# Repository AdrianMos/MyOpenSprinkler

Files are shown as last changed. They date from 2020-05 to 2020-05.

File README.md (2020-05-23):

# myOpenSprinkler
open-source RaspberryPi sprinkler valve controller

This repo includes the KiCad project.

**Features:**
- designed for RaspberryPi Zero W
- small form factor

* inspired by OpenSprinkler Pi project
* supports OpenSprinkler software

- controls 8 zones (8x24VAC valves)
- optical insulation between the power-triacs and RaspberryPi 
- integrated 24VAC to 5V converter (no power connector required for RaspberryPi)
- includes a real-time-clock (RTC) module
- rain sensor input
- transient voltage protection

* connector for RFM12B radio transceiver (used for remote sensing/control)  [drivers not available yet]
* 1-wire communication for connecting external temperature sensors [drivers not available yet]

**Hardware v1.0:**

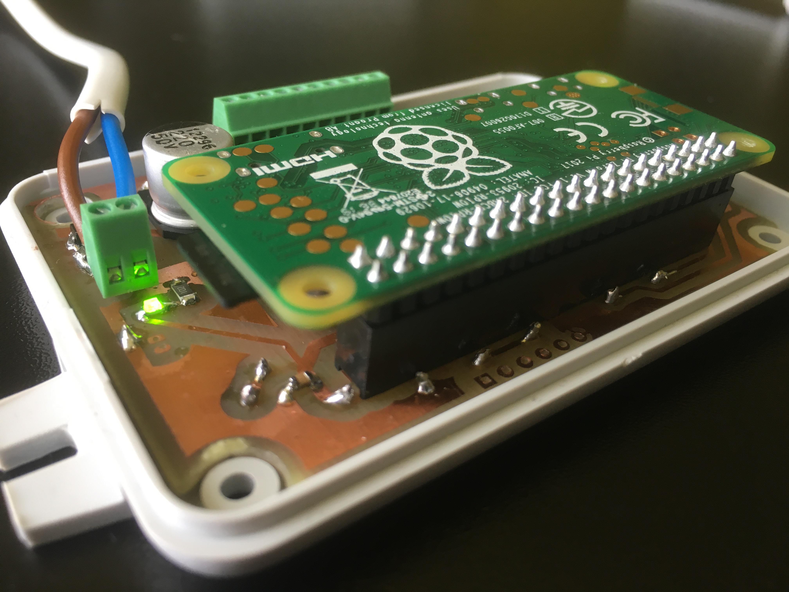
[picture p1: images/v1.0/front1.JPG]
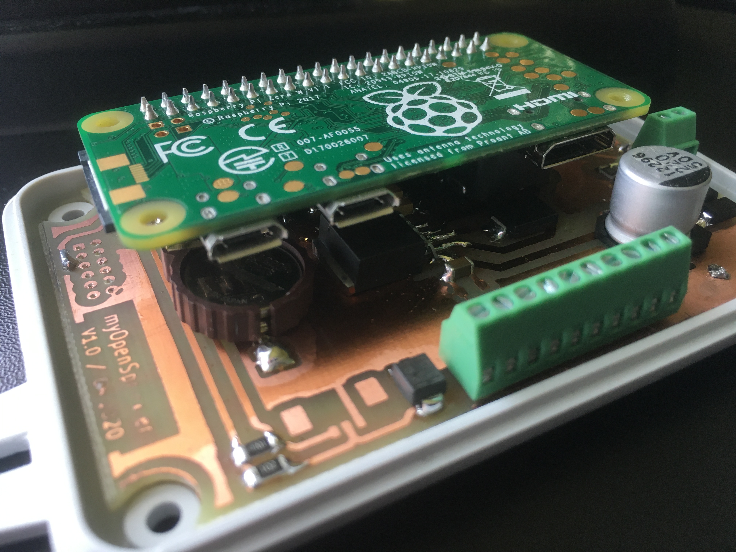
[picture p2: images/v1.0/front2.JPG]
 
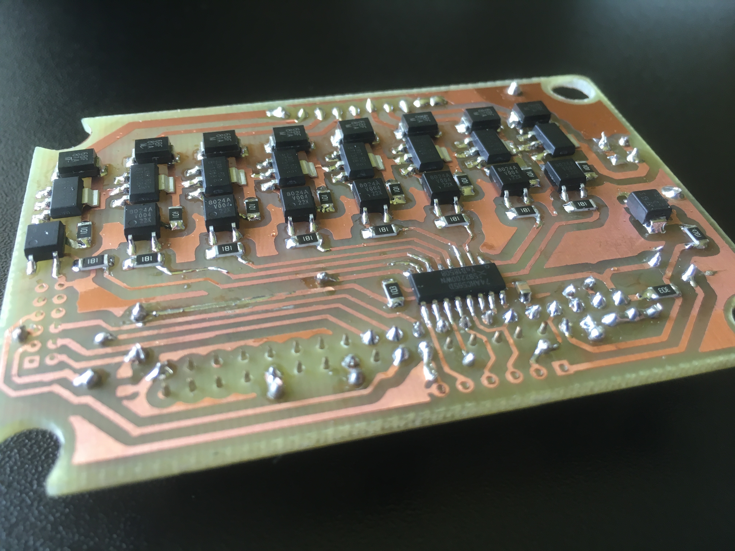
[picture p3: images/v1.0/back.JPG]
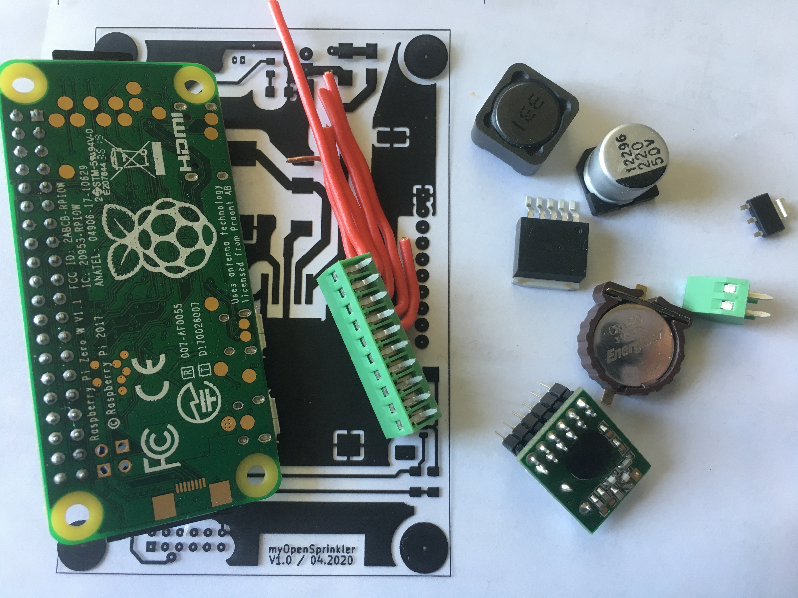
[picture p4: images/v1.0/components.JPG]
 
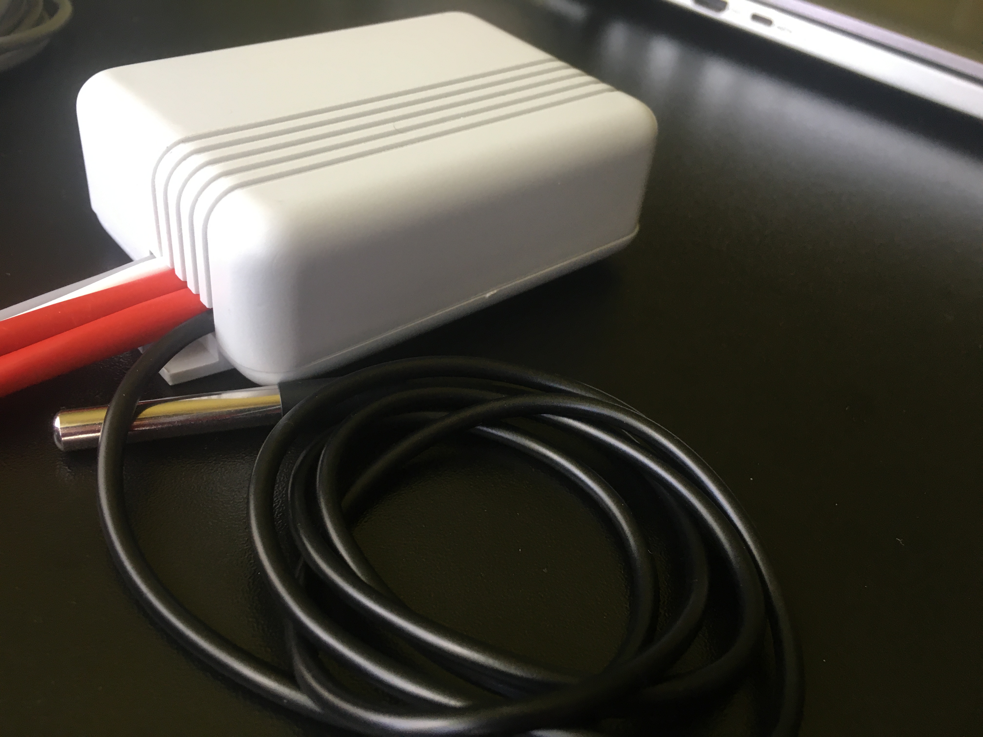
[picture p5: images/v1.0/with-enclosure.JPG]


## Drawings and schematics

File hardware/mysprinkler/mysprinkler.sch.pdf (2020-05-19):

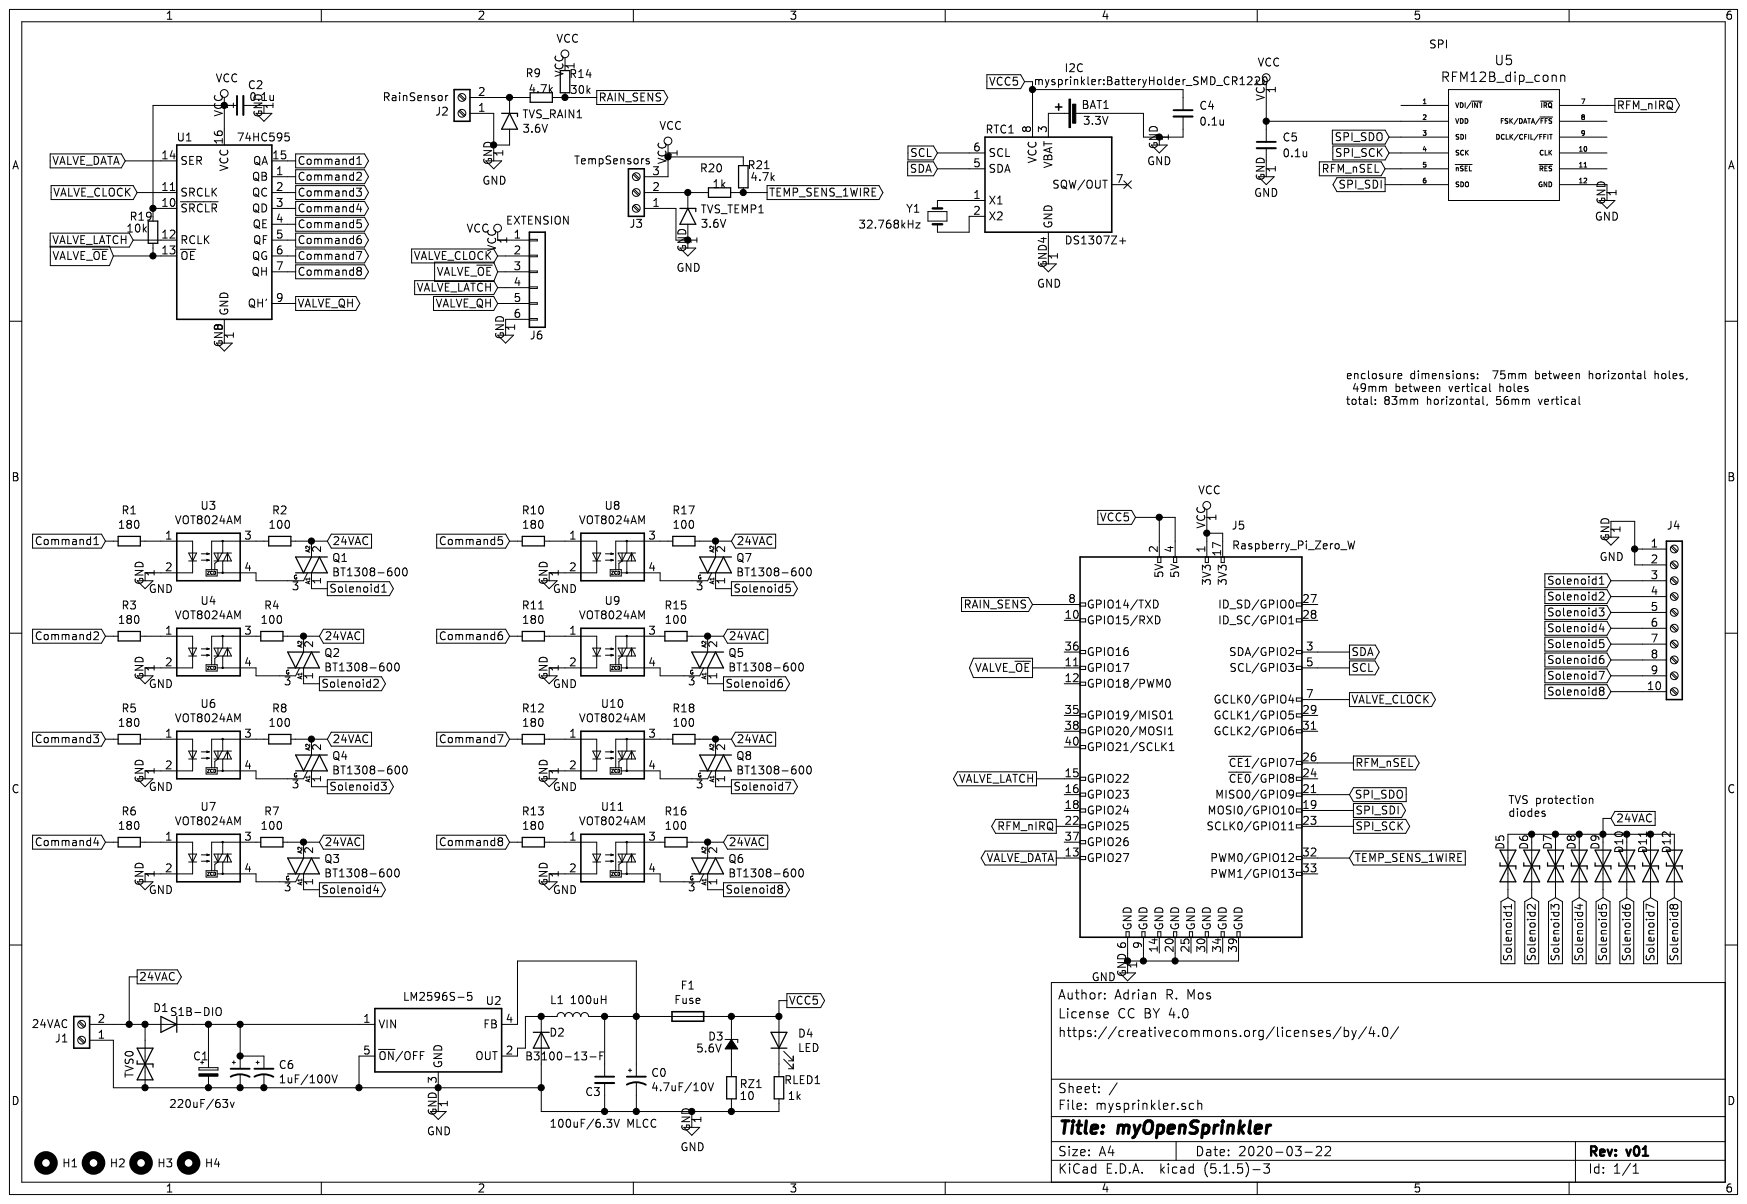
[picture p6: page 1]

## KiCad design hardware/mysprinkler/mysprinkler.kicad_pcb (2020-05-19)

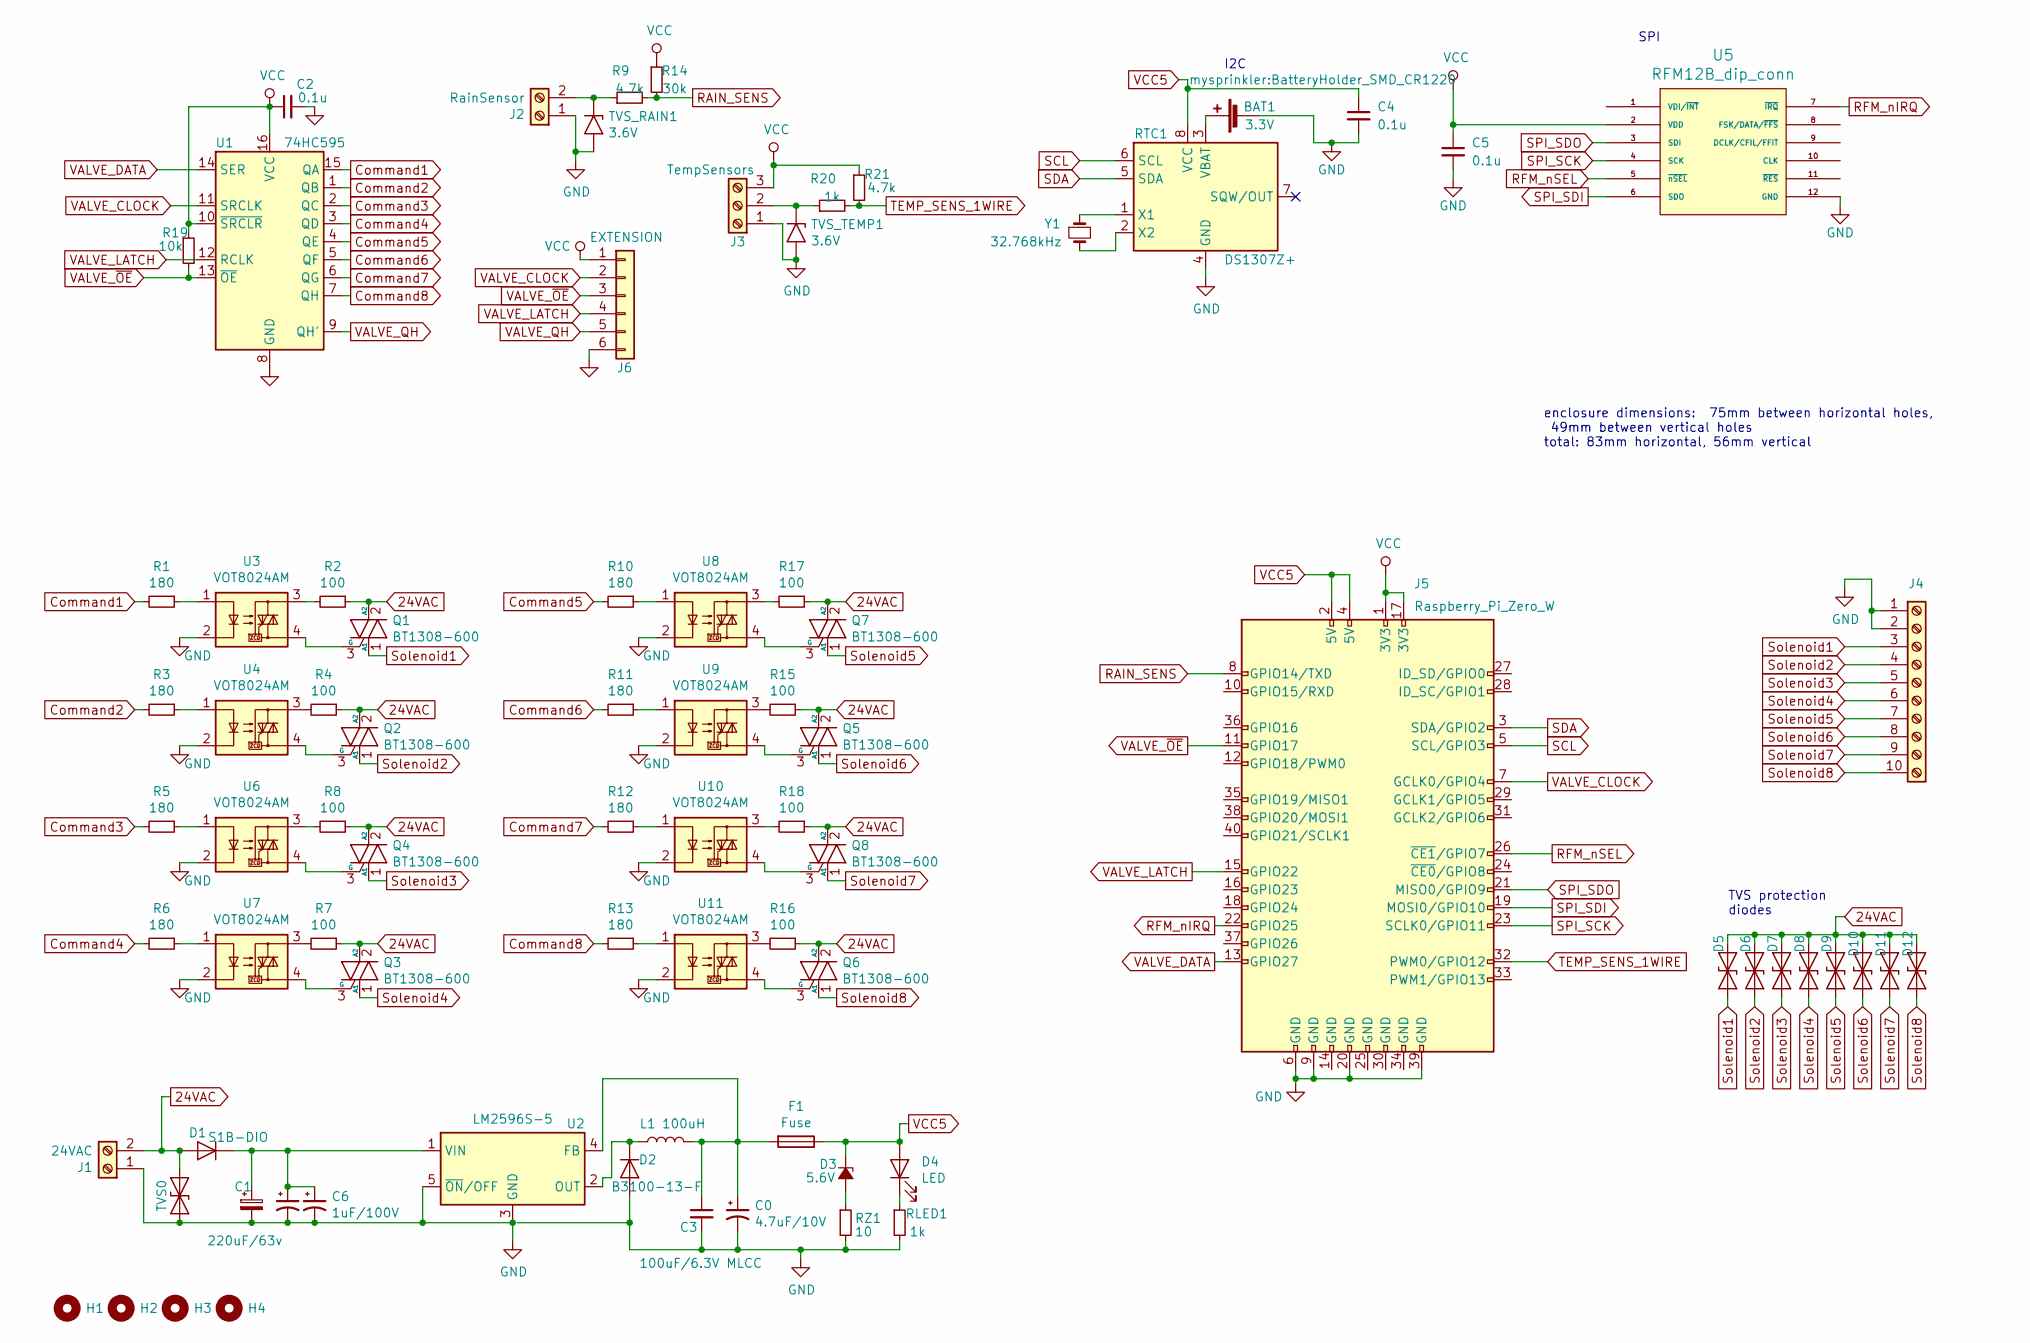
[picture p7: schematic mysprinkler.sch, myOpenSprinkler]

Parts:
BAT1: 3.3V; BatteryHolder_SMD_CR1220
C0: 4.7uF/10V; CP_EIA-3216-18_Kemet-A_Pad1.58x1.35mm_HandSolder
C1: 220uF/63v; C_Elec_10x10.2
C2, C4, C5: 0.1u; C_0805_2012Metric_Pad1.15x1.40mm_HandSolder
C3: 100uF/6.3V MLCC; CP_EIA-3528-21_Kemet-B_Pad1.50x2.35mm_HandSolder
C6: 1uF/100V; C_1206_3216Metric
C6b1: 2.2uF/100V; C_1206_3216Metric
D1: S1B-DIO; D_SMA
D2: B3100-13-F; D_SMC
D3: 5.6V; D_MiniMELF
D4: LED; LED_0805_2012Metric_Pad1.15x1.40mm_HandSolder
D5, D6, D7, D8, D9, D10, D11, D12: D_TVS; D_SMB
F1: Fuse; R_1812_4532Metric_Pad1.30x3.40mm_HandSolder
H1: MH1; MountingHole_6.4mm_M6
H2: 2; MountingHole_6.4mm_M6
H3: 3; MountingHole_6.4mm_M6
H4: 4; MountingHole_6.4mm_M6
J1: 24VAC; TerminalBlock_TE_282834-2_1x02_P2.54mm_Horizontal
J2: RainSensor; Molex_PicoBlade_53047-0210_1x02_P1.25mm_Vertical
J3: TempSensors; Molex_PicoBlade_53398-0371_1x03-1MP_P1.25mm_Vertical
J4: Screw_Terminal_01x10; TerminalBlock_TE_1-282834-0_1x10_P2.54mm_Horizontal
J5: Raspberry_Pi_Zero_W; RaspberryPi_connector_female
J6: EXTENSION; PinHeader_1x06_P2.54mm_Vertical
L1: 100uH; L_12x12mm_H8mm
Q1, Q2, Q3, Q4, Q5, Q6, Q7, Q8: BT1308-600; SOT-223-3_TabPin2
R1, R3, R5, R6, R10, R11, R12, R13: 180; R_1206_3216Metric_Pad1.42x1.75mm_HandSolder
R2, R4, R7, R8, R15, R16, R17, R18: 100; R_1206_3216Metric_Pad1.42x1.75mm_HandSolder
R9, R21: 4.7k; R_1206_3216Metric_Pad1.42x1.75mm_HandSolder
R14: 30k; R_1206_3216Metric_Pad1.42x1.75mm_HandSolder
R19: 10k; R_1206_3216Metric_Pad1.42x1.75mm_HandSolder
R20: 1k; R_1206_3216Metric_Pad1.42x1.75mm_HandSolder
RLED1: 1k; R_1206_3216Metric_Pad1.42x1.75mm_HandSolder
RTC1: DS1307Z+; SOIC-8_3.9x4.9mm_P1.27mm
RZ1: 10; R_1206_3216Metric_Pad1.42x1.75mm_HandSolder
TVS0: D_TVS; D_SMB
TVS_RAIN1: 3.6V; D_SMB
TVS_TEMP1: 3.6V; D_SMB
U1: 74HC595; SOIC-16_3.9x9.9mm_P1.27mm
U2: LM2596S-5; TO-263-5_TabPin3
U3, U4, U6, U7, U8, U9, U10, U11: VOT8024AM; SO-4_4.4x4.3mm_P2.54mm_handsolder
U5: RFM12B_dip_conn; PinSocket_2x06_P2.00mm_Vertical
Y1: 32.768kHz; Crystal_SMD_EuroQuartz_EQ161-2Pin_3.2x1.5mm_HandSoldering

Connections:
24VAC: D1.2 (A), D5.2 (A2), D6.2 (A2), D7.2 (A2), D8.2 (A2), D9.2 (A2), D10.2 (A2), D11.2 (A2), D12.2 (A2), J1.2, Q1.2 (A2), Q2.2 (A2), Q3.2 (A2), Q4.2 (A2), Q5.2 (A2), Q6.2 (A2), Q7.2 (A2), Q8.2 (A2), R2.1, R4.1, R7.1, R8.1, R15.1, R16.1, R17.1, R18.1, TVS0.2 (A2)
Command1: R1.2, U1.15 (QA)
Command2: R3.2, U1.1 (QB)
Command3: R5.2, U1.2 (QC)
Command4: R6.2, U1.3 (QD)
Command5: R10.2, U1.4 (QE)
Command6: R11.2, U1.5 (QF)
Command7: R12.2, U1.6 (QG)
Command8: R13.2, U1.7 (QH)
GND: BAT1.2 (-), C0.2, C1.2, C2.2, C3.2, C4.2, C5.2, C6.2, C6b1.2, D2.2 (A), J1.1, J2.1, J3.1, J4.1, J4.2, J5.6 (GND), J5.9 (GND), J5.20 (GND), J5.39 (GND), J6.6, RLED1.2, RTC1.4 (GND), RZ1.2, TVS0.1 (A1), TVS_RAIN1.2 (A2), TVS_TEMP1.2 (A2), U1.8 (GND), U2.3 (GND), U2.5 (~ON~/OFF), U3.2, U4.2, U5.12 (GND), U6.2, U7.2, U8.2, U9.2, U10.2, U11.2
unnamed: BAT1.1 (+), RTC1.3 (VBAT)
unnamed: C0.1, C3.1, F1.2, L1.2, U2.4 (FB)
unnamed: C1.1, C6.1, C6b1.1, D1.1 (K), U2.1 (VIN)
unnamed: D2.1 (K), L1.1, U2.2 (OUT)
unnamed: D3.2 (A), RZ1.1
unnamed: D4.1 (K), RLED1.1
unnamed: J2.2, R9.1, TVS_RAIN1.1 (A1)
unnamed: J3.2, R20.1, TVS_TEMP1.1 (A1)
unnamed: Q1.3 (G), U3.4
unnamed: Q2.3 (G), U4.4
unnamed: Q3.3 (G), U7.4
unnamed: Q4.3 (G), U6.4
unnamed: Q5.3 (G), U9.4
unnamed: Q6.3 (G), U11.4
unnamed: Q7.3 (G), U8.4
unnamed: Q8.3 (G), U10.4
unnamed: R1.1, U3.1
unnamed: R2.2, U3.3
unnamed: R3.1, U4.1
unnamed: R4.2, U4.3
unnamed: R5.1, U6.1
unnamed: R6.1, U7.1
unnamed: R7.2, U7.3
unnamed: R8.2, U6.3
unnamed: R10.1, U8.1
unnamed: R11.1, U9.1
unnamed: R12.1, U10.1
unnamed: R13.1, U11.1
unnamed: R15.2, U9.3
unnamed: R16.2, U11.3
unnamed: R17.2, U8.3
unnamed: R18.2, U10.3
unnamed: RTC1.1 (X1), Y1.1
unnamed: RTC1.2 (X2), Y1.2
RAIN_SENS: J5.8 (GPIO14/TXD), R9.2, R14.2
RFM_nIRQ: J5.22 (GPIO25), U5.7 (~IRQ)
RFM_nSEL: J5.26 (~CE1~/GPIO7), U5.5 (~nSEL)
SCL: J5.5 (SCL/GPIO3), RTC1.6 (SCL)
SDA: J5.3 (SDA/GPIO2), RTC1.5 (SDA)
SPI_SCK: J5.23 (SCLK0/GPIO11), U5.4 (SCK)
SPI_SDI: J5.19 (MOSI0/GPIO10), U5.6 (SDO)
SPI_SDO: J5.21 (MISO0/GPIO9), U5.3 (SDI)
Solenoid1: D5.1 (A1), J4.3, Q1.1 (A1)
Solenoid2: D6.1 (A1), J4.4, Q2.1 (A1)
Solenoid3: D7.1 (A1), J4.5, Q4.1 (A1)
Solenoid4: D8.1 (A1), J4.6, Q3.1 (A1)
Solenoid5: D9.1 (A1), J4.7, Q7.1 (A1)
Solenoid6: D10.1 (A1), J4.8, Q5.1 (A1)
Solenoid7: D11.1 (A1), J4.9, Q8.1 (A1)
Solenoid8: D12.1 (A1), J4.10, Q6.1 (A1)
TEMP_SENS_1WIRE: J5.32 (PWM0/GPIO12), R20.2, R21.2
VALVE_CLOCK: J5.7 (GCLK0/GPIO4), J6.2, U1.11 (SRCLK)
VALVE_DATA: J5.13 (GPIO27), U1.14 (SER)
VALVE_LATCH: J5.15 (GPIO22), J6.4, U1.12 (RCLK)
VALVE_QH: J6.5, U1.9 (QH')
VALVE_~OE: J5.11 (GPIO17), J6.3, R19.2, U1.13 (~OE)
VCC: C2.1, C5.1, J3.3, J5.1 (3V3), J5.17 (3V3), J6.1, R14.1, R19.1, R21.1, U1.10 (~SRCLR), U1.16 (VCC), U5.2 (VDD)
VCC5: C4.1, D3.1 (K), D4.2 (A), F1.1, J5.2 (5V), J5.4 (5V), RTC1.8 (VCC)

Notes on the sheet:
TVS protection diodes
I2C
SPI
enclosure dimensions: 75mm between horizontal holes, 49mm between vertical holes total: 83mm horizontal, 56mm vertical

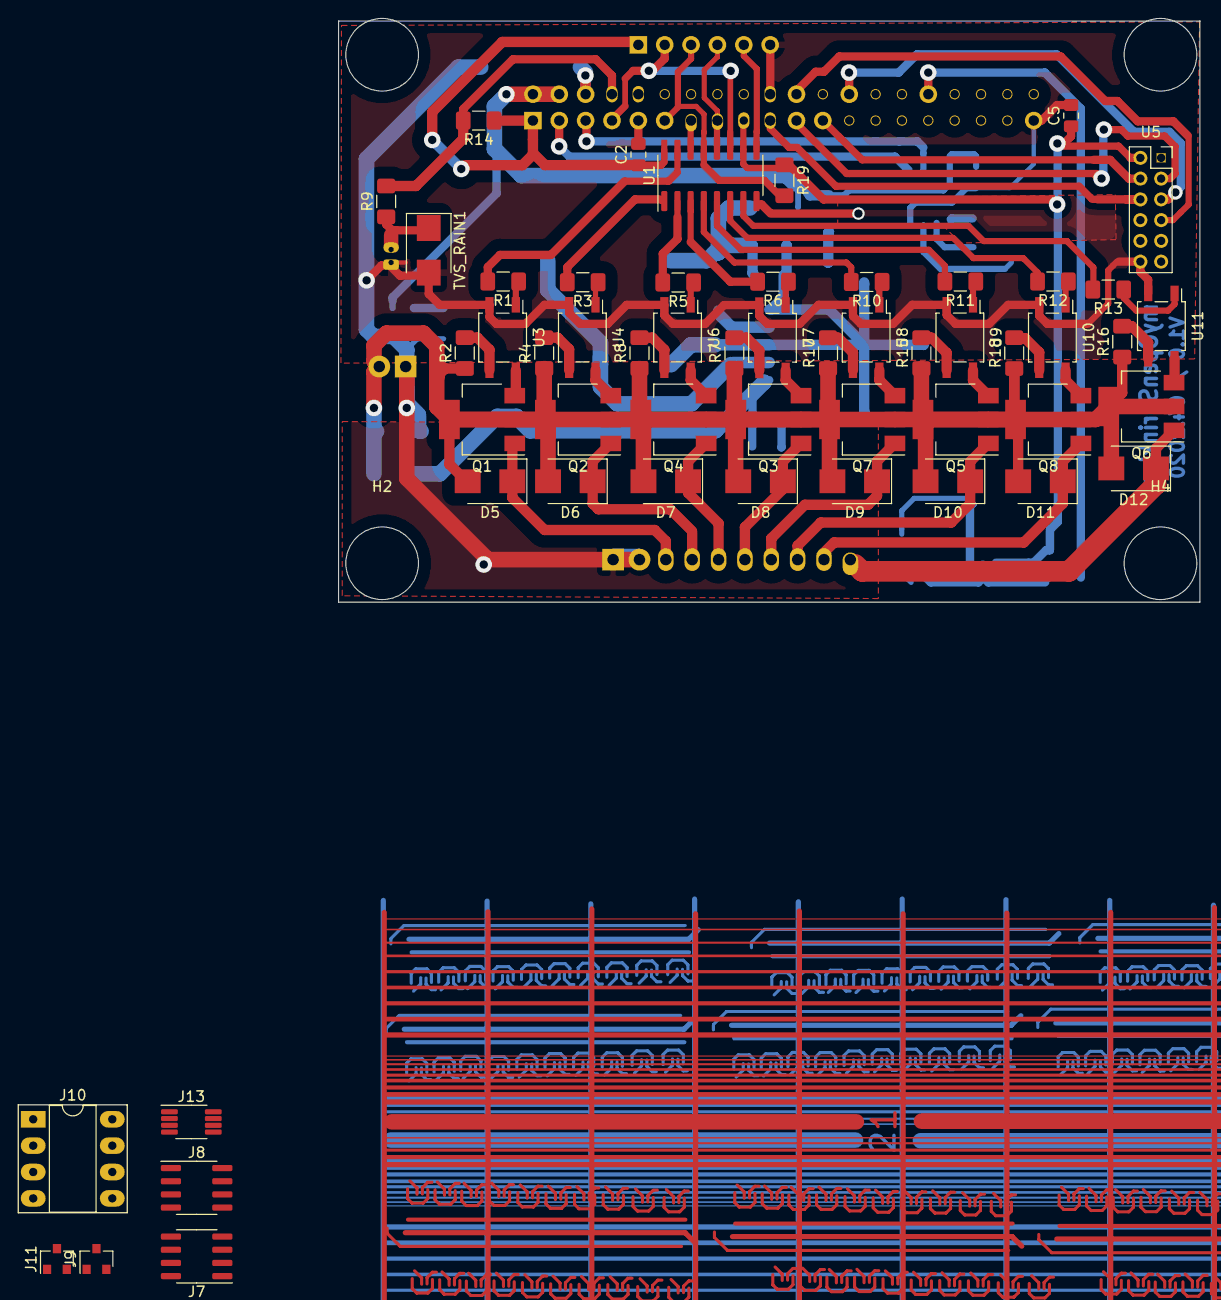
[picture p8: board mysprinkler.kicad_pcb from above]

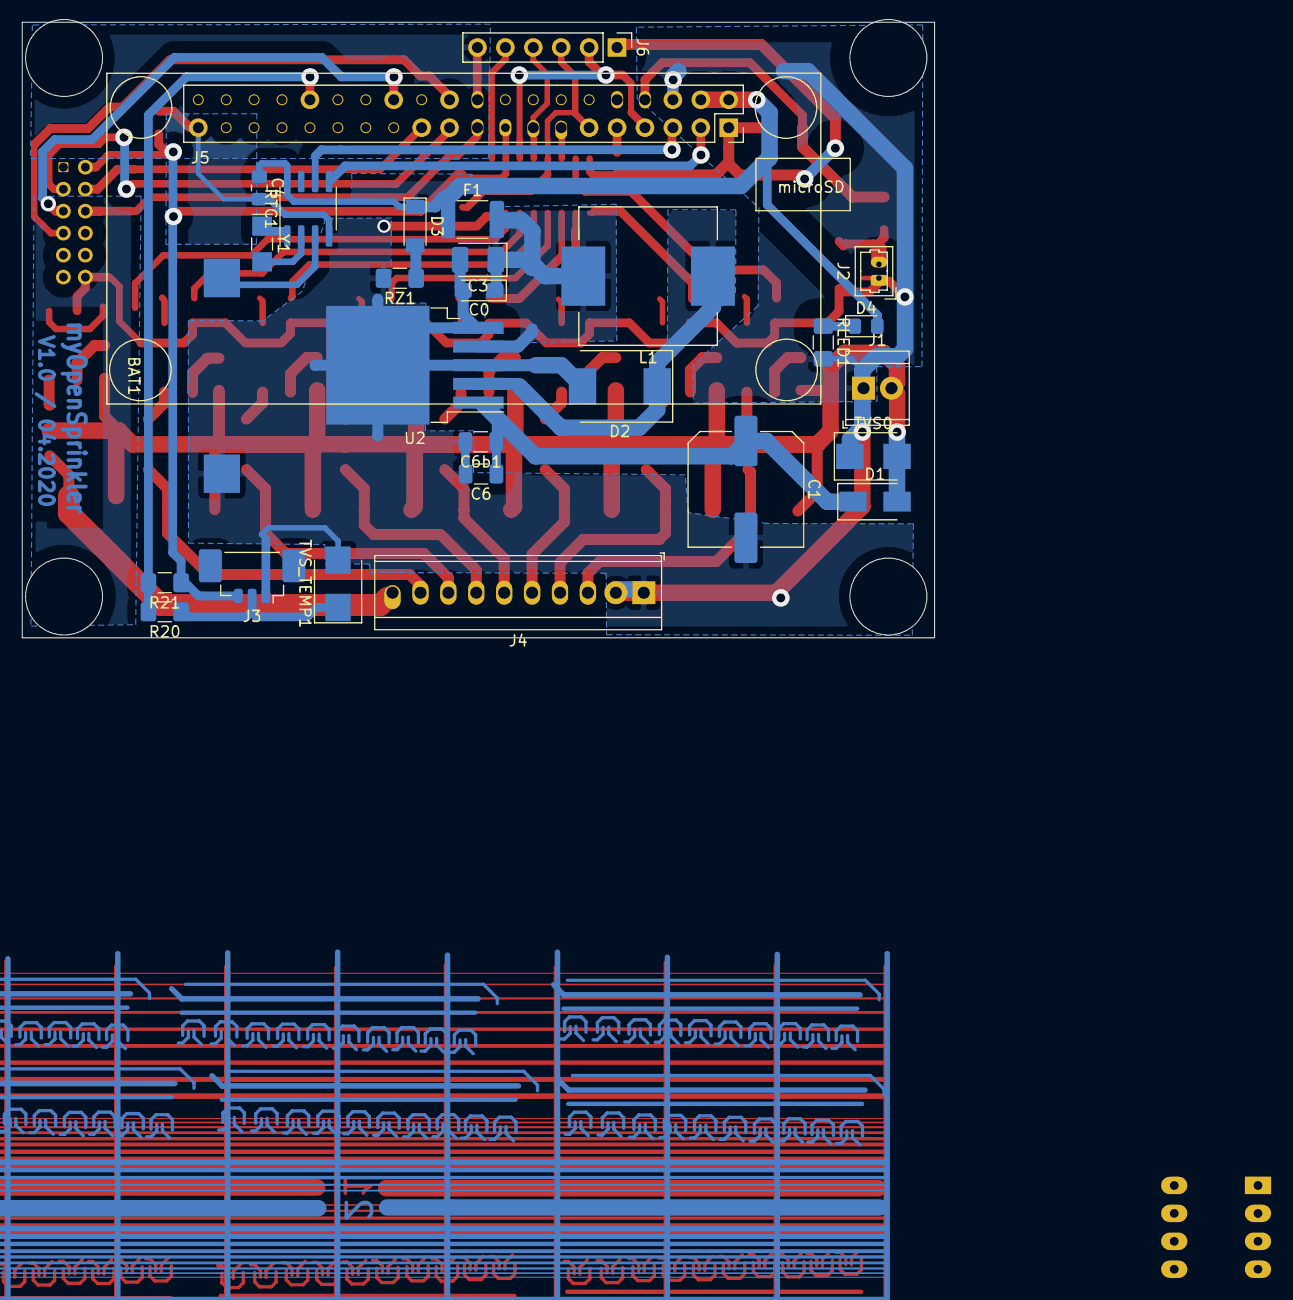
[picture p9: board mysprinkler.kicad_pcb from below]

Board: 2 copper layers, 83.0 x 56.0 mm, 86 parts (28 on the bottom side), 68 nets.

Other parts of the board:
J7, J8: SOIC8; SOIC-8_3.9x4.9mm_P1.27mm
J9, J11: SOT23; SOT-23
J10: DIP8; DIP-8_W7.62mm_Socket_LongPads
J13: MSOP8; MSOP-8_3x3mm_P0.65mm

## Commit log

2020-05-20 images for v1.0 board
2020-05-23 case closed image

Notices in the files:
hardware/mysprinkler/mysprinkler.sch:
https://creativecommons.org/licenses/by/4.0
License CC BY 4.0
